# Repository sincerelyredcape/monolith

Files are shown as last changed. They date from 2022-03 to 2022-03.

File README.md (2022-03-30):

# monolith
A southpaw battlestation in stainless steel with a novel encoder solution.

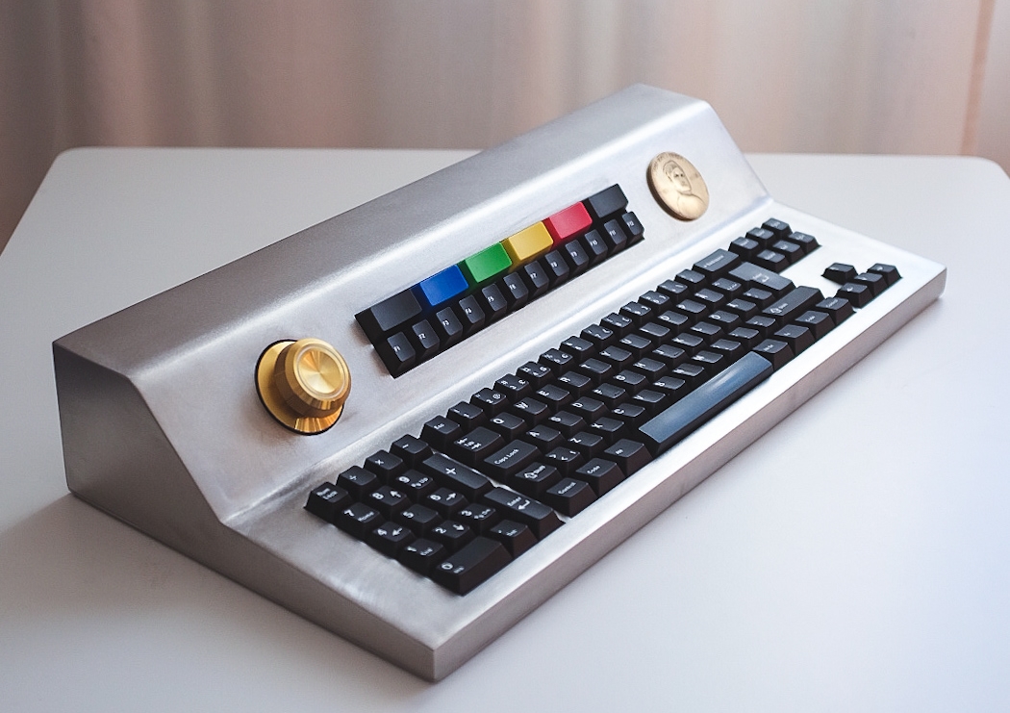
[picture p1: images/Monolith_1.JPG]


Two more pics at the bottom, didn't have time to snap more before delivery.

## Introduction
In this walkthrough I will, to the best of my ability, explain my entire build process in detail from start to finish. I'll be documenting this process for you *and* me, so bear with me when I start explaining things that are irrelevant to most people. While the parts used are available here for anyone to use, you would know after reading this entire "guide" that the sensible thing to do is to learn from my process and design a keyboard that is your own. 

In the unlikely case that anyone wants to build a replica, there are several improvements that should be implemented beforehand. More on those [here](#improvements-and-issues).

Let me know if I can elaborate on something! Shoot me message on [Reddit](https://www.reddit.com/user/sincerelyredcape) or on Discord where I go by sincerelyredcape#2148.

## Case design
I only had one real requirement for this build, a good knob. A second requirement I set for myself was for it to be comically heavy. However, milled steel doesn't come cheap and I wasnt looking for spending an entire months salary on a keyboard (just yet). I recently finished building a motorcycle so while the TIG-welder was still hot I thought that laser cut metal plates would reduce the materials cost significantly if I could weld something together.

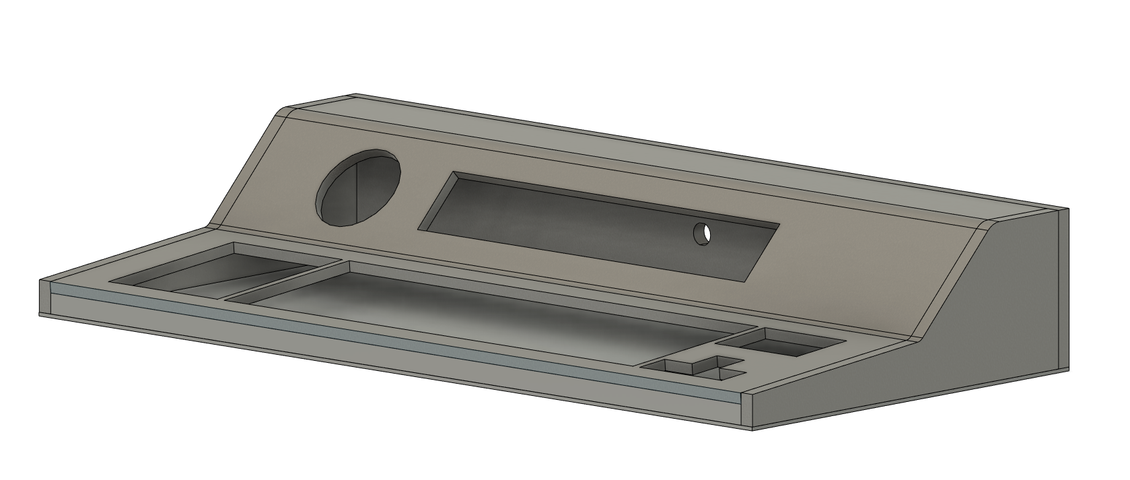
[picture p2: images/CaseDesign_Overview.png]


With my limited knowledge of Fusion 360 I put this together with the sheet metal workflow. The top part is 6mm thick, the walls are 8mm and the bottom plate is 2mm. The top is 6mm because I wanted to use a burger mounted switch place with thick, soft [grommet](https://www.digikey.se/sv/products/detail/3m-aearo-technologies-llc/G-410-V2599/6226897) to reduce sound as much as possible. The grommet builds another 1-2mm which places the top of the switch plate at approximately 7.5mm from top of case. This occludes the keycap edges. The back got a hole to accomodate a Weipu SF12 connector that seemed to fit the theme of this build.

## Case construction
All parts were ordered from Fractory, which was a delightful experience. Just upload the parts you need, with bends and all, and they ship it out to you in about ten days. It's great if you don't have any local connections with those capabilities. All in all case parts with shipping and VAT costs about €329 today, but I ordered a *lot* of stuff for my motorcycle which lowered the overall price somewhat. I paid roughly half of that because of the reason above and sky-rocketing steel prices since the beginning of 2021.

Title

Before welding I had to make threaded holes that would accept the [shoulder bolts](https://www.digikey.se/en/products/detail/SB-4105/EAR1237-ND/6226887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) for the switch plates and encoder mount. I printed out alignment pieces that went into the switch plate, laid it down in the case and center-punched every hole. In hindsight I should've had Fractory mark out the hole centers while it was under the laser.

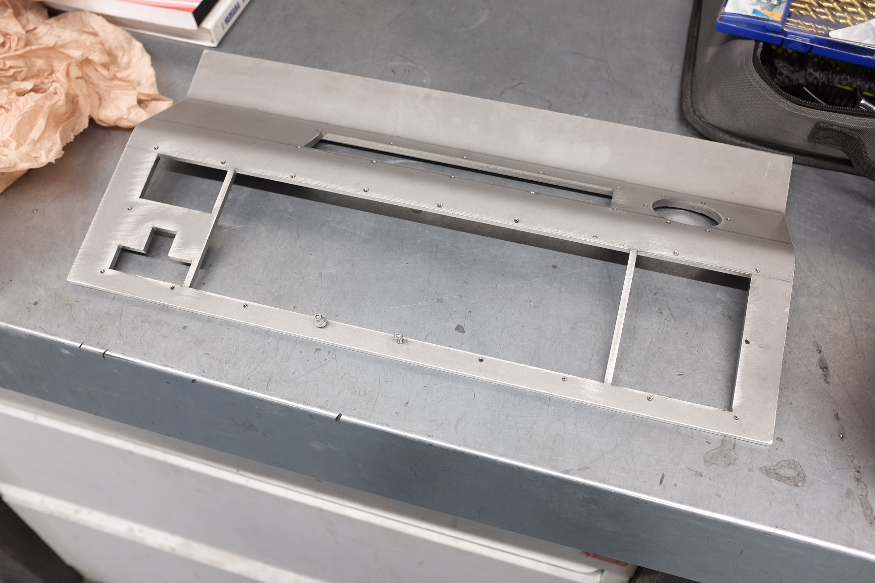
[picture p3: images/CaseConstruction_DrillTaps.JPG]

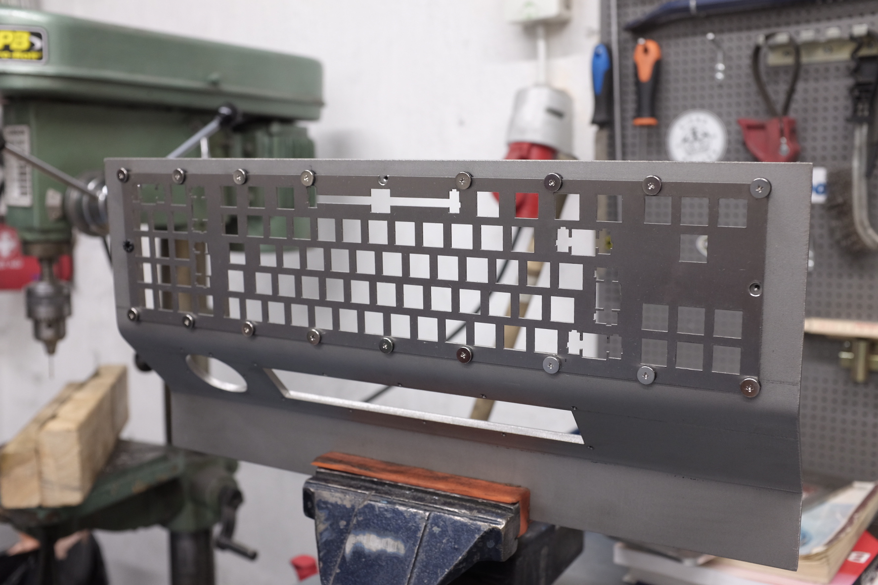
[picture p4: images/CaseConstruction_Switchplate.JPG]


 I also had to make a counterbore in the back plate before welding because the Weipu connector didn't work on a 8mm panel, it shows two pictures down. But first, here are some shitty welds for you:

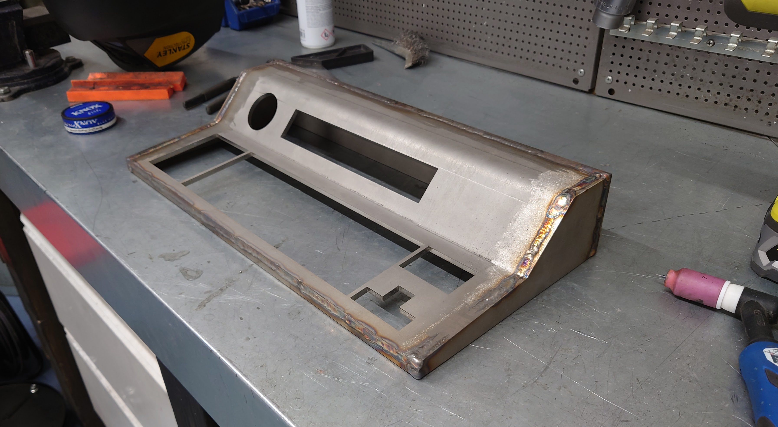
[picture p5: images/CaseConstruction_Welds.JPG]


After this I temporarily spot-welded the bottom plate so I could drill holes in the case walls. This too, should've been marked on the bottom plate. No picture of this unfortunately.

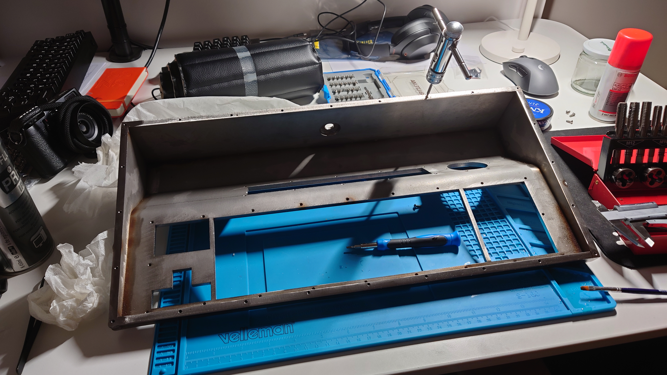
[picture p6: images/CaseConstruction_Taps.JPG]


I then tapped all holes in M3. If you're not familiar, 304 Stainless is among the toughest materials to tap and doing this I wore out three taps, broke another three taps, one tap extractor and two very nice drill bits to a total cost of about €92. :-)

A small detail to add is that the walls didn't end up completely flat on the bottom because I wasn't paying attention during welding. I had to file them flat later on.

Finally, the case was finished with an orbital sander for a uniform look.

# Volume knob
Ah, what you came here for. 

Long story long, I started out by ordering some EC11 encoders because that's what everybody uses. It became evident quickly that they weren't up to the task because one, they arent sturdy enough to feel nice with a heavy aluminium knob. And two, the detents would barely register. I then found [this](https://www.aliexpress.com/wholesale?catId=0&initiative_id=SB_20220327141316&SearchText=omron+encoder) on AliExpres, it looked the part so I ordered two, one with 20PPR and one with 30PPR. With these two I could freely pick 10, 15, 20, 30 or 40 detents in software later on. The shaft is very rigid, there's no play whatsoever. It is likely supported by two bearings inside. 

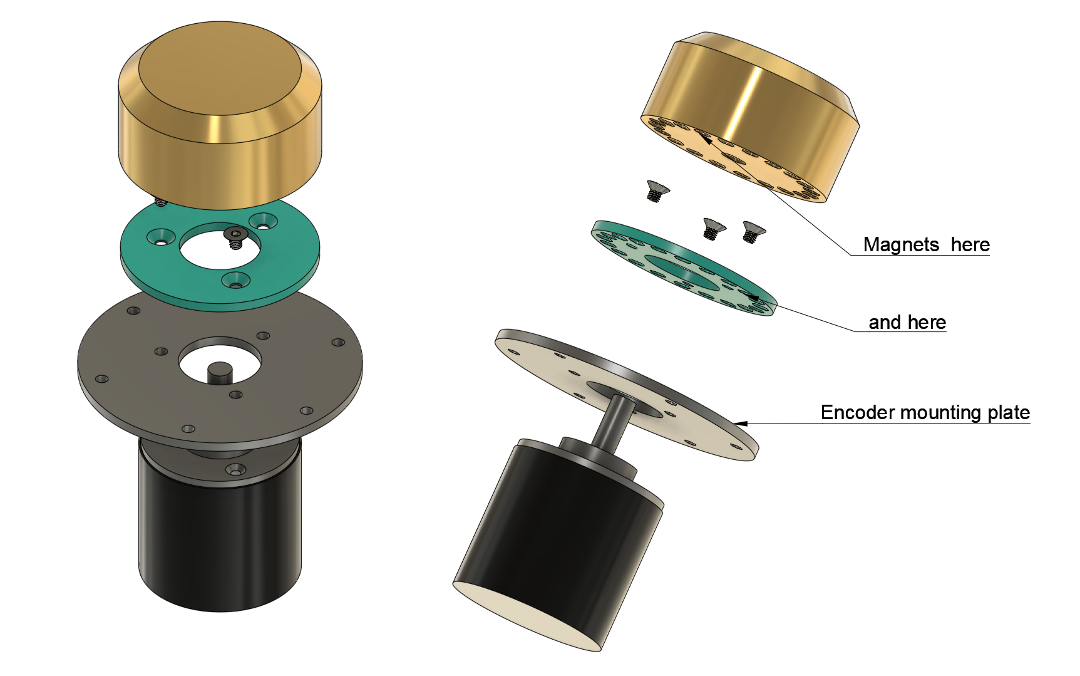
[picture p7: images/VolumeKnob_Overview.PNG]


I hope the schematic explains most of it, but to make detents for the smooth encoder I 3D printed a disc (in green) that holds twenty neodymium magnets and drilled holes for another twenty magnets in the knob. If you prefer to (or can't) drill holes in the knob you could always print another disc and glue it semi-permanently to the knob. All magnets are mounted in the same polarity orientation in the disc, opposite polarity in the knob so that the disc and knob arrays attract. Use some glue to seal the magnets in place, I used epoxy for the disc and superglue for the knob.

In summary, I think this detent solution turned out great for a big knob. It has, however a tiny jiggle before it seats in a detent when you freewhel it and let it stop on its own. But I think that could be solved with a rubber shim, less detents, lighter knob or bigger magnets. I really don't know, but let me know if you find something out.

# Electronics
Since I have no experience designing PCB's I opted for the handwired route, in hindsight I should've just learned KiCad because it probably would have saved me some time in the end. This is what ~1600 solder joints look like: 

Title

It's got a Teensy++ 2.0 to handle the big matrix that consist of a whole bunch of [Amoeba](https://github.com/mtl/keyboard-pcbs/tree/master/amoeba) PCB's. It also has full backlight, powered by a mosfet and PWM.

# Improvements and issues
- Switch plate is too close to the front case wall, my shoulder bolts rubbed against the wall. It worked out, but it was too close for comfort.
- Knob cutout is very close to the bend for this plate thickness which resulted in some warping of the hole.
- Marking out hole centers by hand was difficult and introduced a margin of error in the switch plate alignment. I should have put in laser marking data to have the manufacturer pinpoint the hole centers on all holes to be drilled. Or even better, have the manufacturer drill all holes to a depth of 5mm.
- Design a proper PCB.
- Make keys on the case parts for self-aligment. Like [this](https://solid-blog.pl/wp-content/uploads/2021/07/1.07.2021-3.jpg)

# Pictures
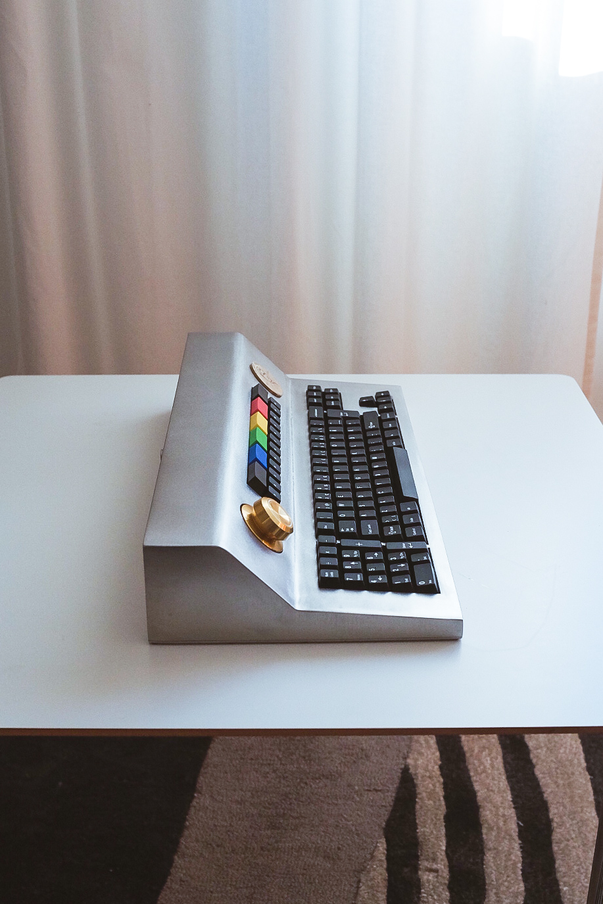
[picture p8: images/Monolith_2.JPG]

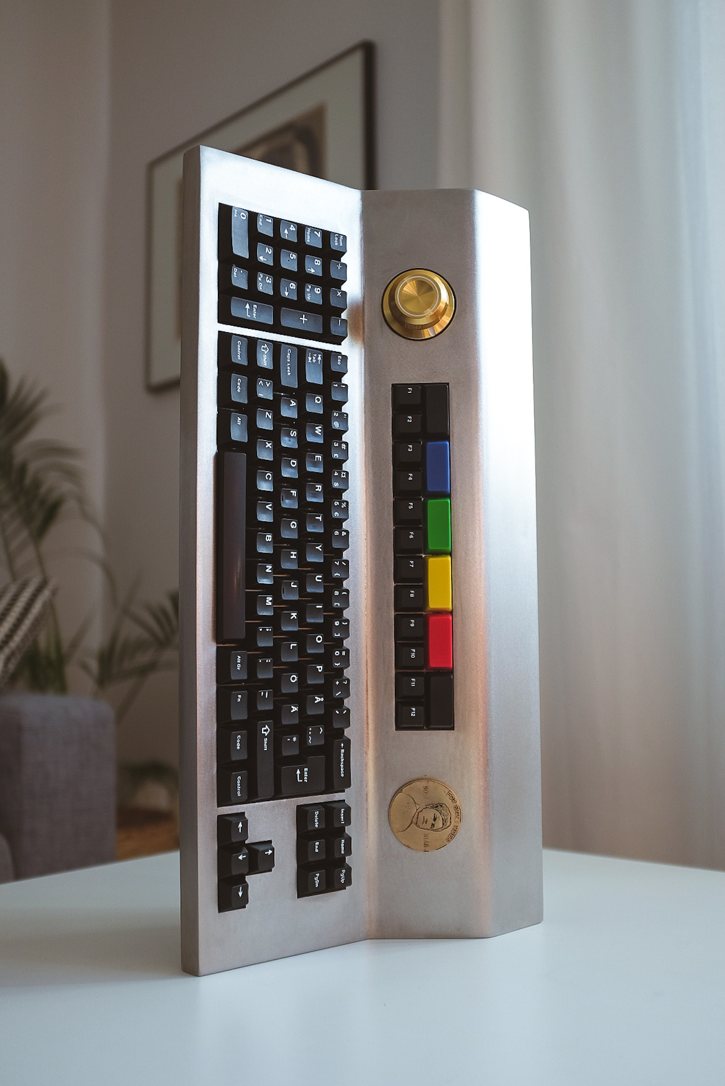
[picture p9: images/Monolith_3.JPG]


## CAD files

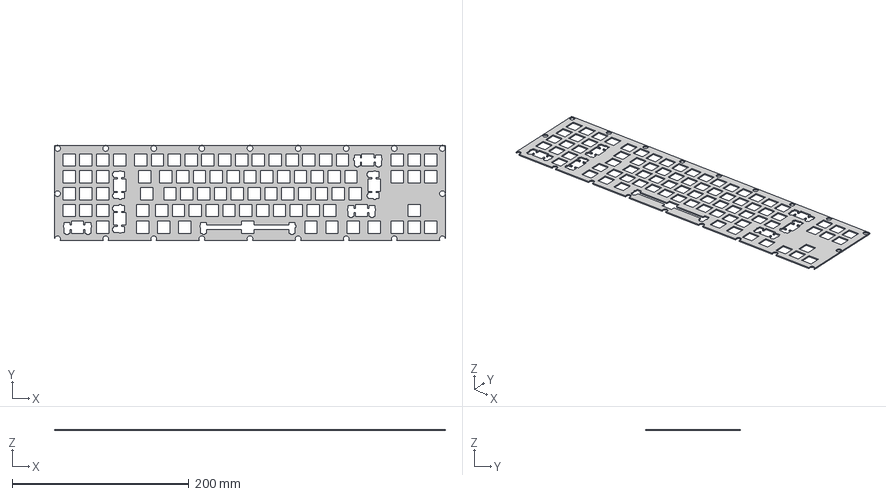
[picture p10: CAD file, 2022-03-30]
monolith_parts/Switch plate main.step
442.6 x 107.8 x 1.50 mm
Switch layer
Front wall

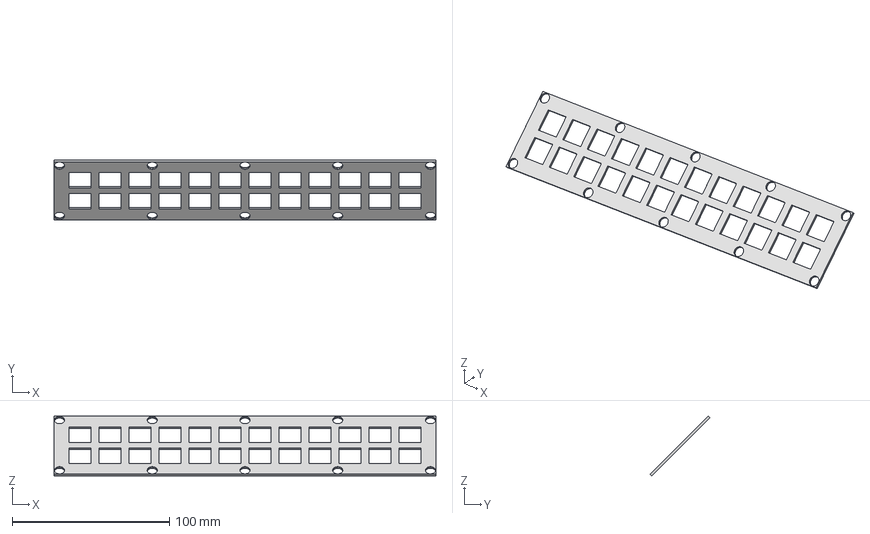
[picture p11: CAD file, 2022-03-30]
monolith_parts/Switch plate function rows.step
242.6 x 37.9 x 37.9 mm
Switch layer
Front wall

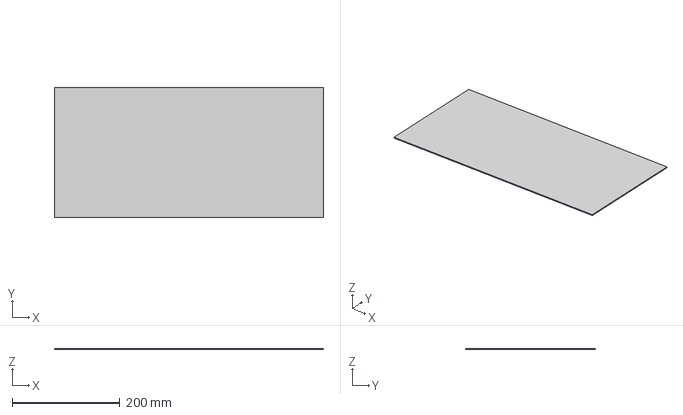
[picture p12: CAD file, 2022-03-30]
monolith_parts/Bottom plate.step
498.6 x 240.4 x 2.00 mm

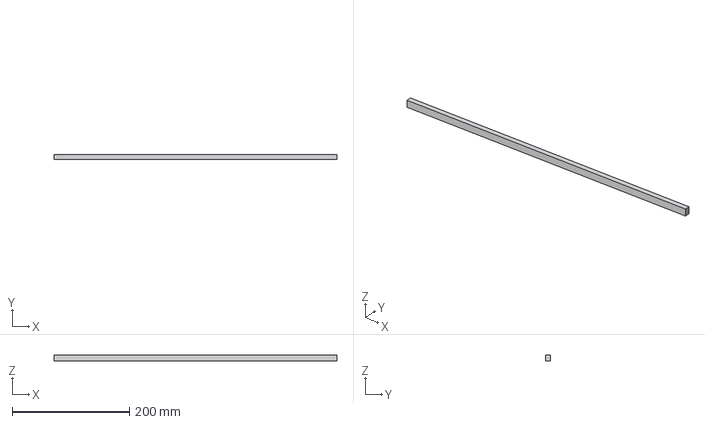
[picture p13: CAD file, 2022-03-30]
monolith_parts/Case front.step
482.6 x 8.00 x 11.0 mm

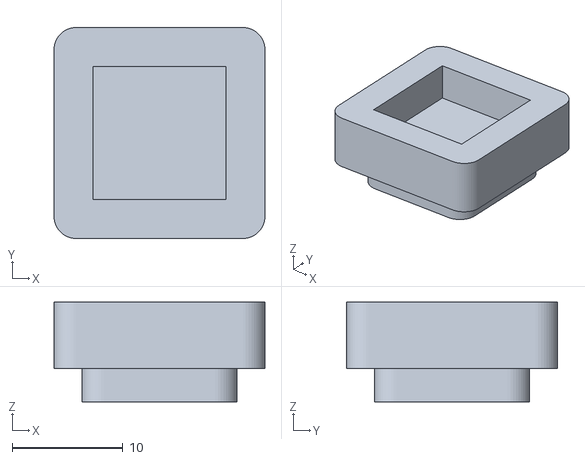
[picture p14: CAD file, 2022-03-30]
monolith_parts/Plate alignment part.stl
19.0 x 19.0 x 9.00

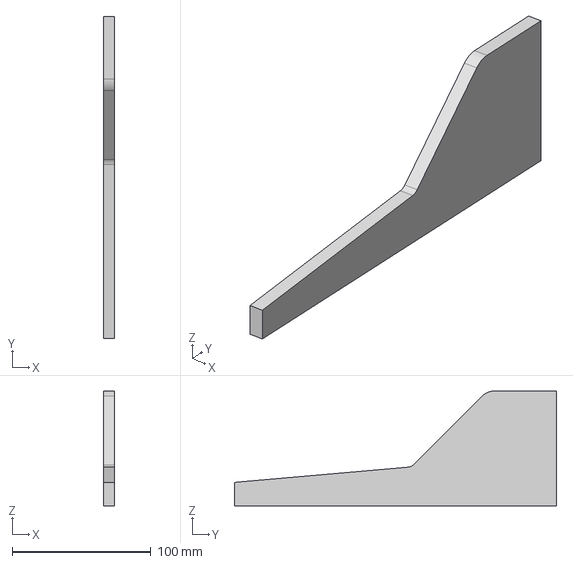
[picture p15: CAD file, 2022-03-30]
monolith_parts/Case side.step
8.00 x 232.1 x 82.8 mm

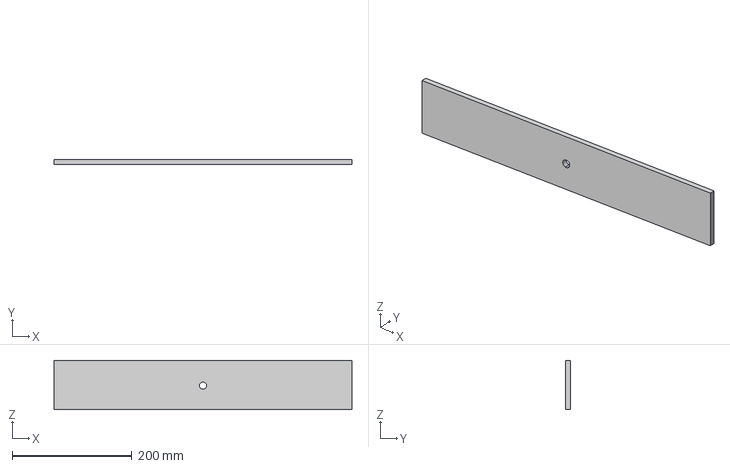
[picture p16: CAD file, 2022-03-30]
monolith_parts/Case back.step
498.6 x 8.00 x 82.8 mm

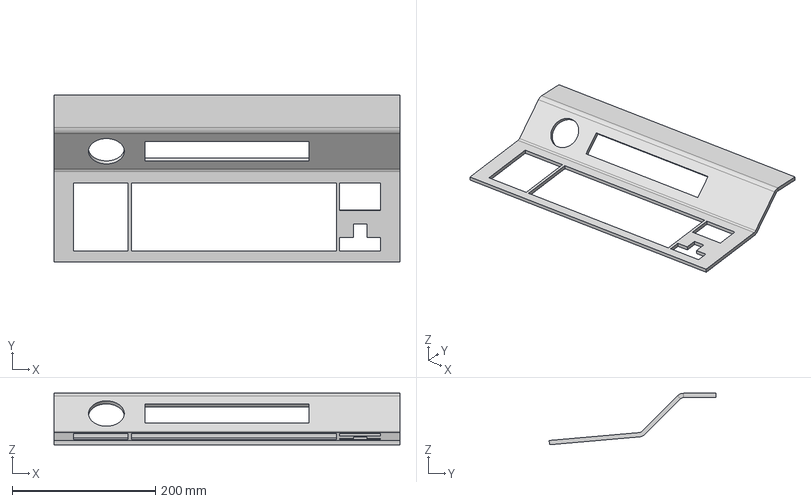
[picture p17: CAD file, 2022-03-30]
monolith_parts/Case top.step
482.6 x 232.7 x 71.9 mm
V2
Front wall

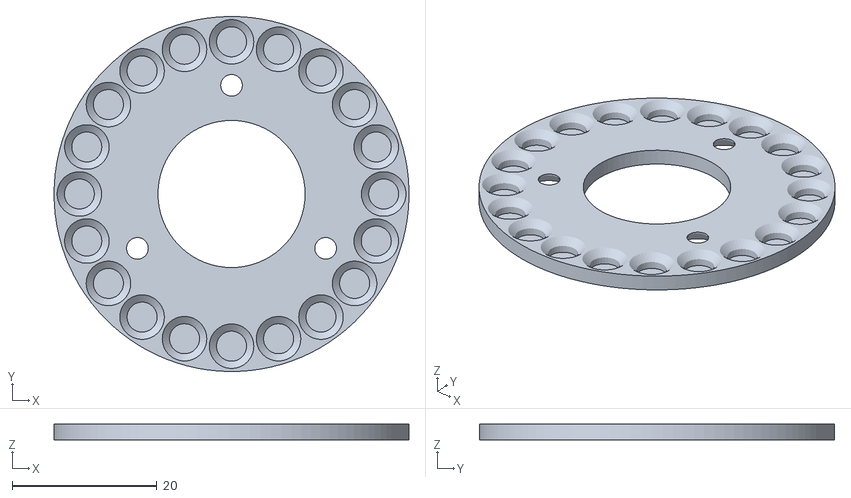
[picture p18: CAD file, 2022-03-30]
monolith_parts/Omron encoder magnet detent disc.stl
49.0 x 49.0 x 2.20

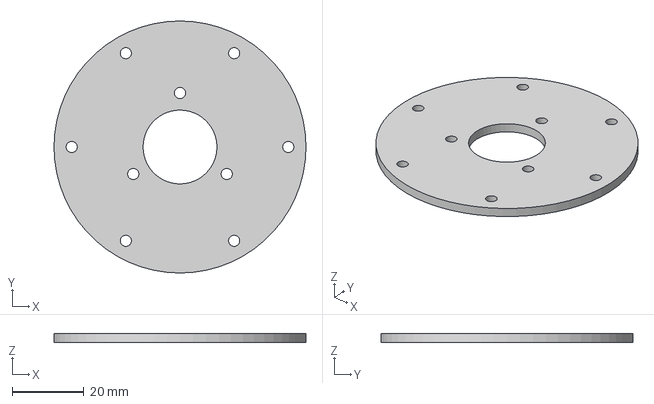
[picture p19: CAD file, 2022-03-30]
monolith_parts/Encoder mounting plate.step
70.0 x 70.0 x 2.50 mm
Front wall
Encoder plate
